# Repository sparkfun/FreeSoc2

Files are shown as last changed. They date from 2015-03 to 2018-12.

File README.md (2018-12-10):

SparkFun FreeSoc2
========================================

FreeSoC2 (https://www.sparkfun.com/products/13714)

[*SparkFun FreeSoC2 (DEV-13714)*](https://www.sparkfun.com/products/13714)

The [FreeSoc2 is SparkFun's PSoC5LP development board](https://www.sparkfun.com/products/13714). It features a full onboard debugger, support for 5V and 3.3V IO voltages, and a CY8C5888AXI-LP096 processor with 256kB of flash, 64kB of SRAM and 2kB of EEPROM. The onboard oscillator can drive the processor at up to 80MHz, and the Cortex-M3 core provides superior performance.

The real power of the PSoC5LP isn't in the processor, however. Wrapped around the processor is a rich analog and digital programmable fabric which can be configured to provide many functions which would otherwise need to be realized in code (lowering system performance) or external circuitry (adding cost and board size). In addition, the highly flexible fabric means that most any function can be routed to most any pin, which makes this a wonderful tool for development and allows board layout errors to be solved, at least temporarily, pretty easily.

Repository Contents
-------------------

* **/Hardware** - Eagle design files (.brd, .sch)
* **/Production** - Production panel files (.brd)

Documentation
--------------
* **[Arduino Board Support](https://github.com/sparkfun/PSoC_Arduino_Support)** - Support board files for adding the FreeSoC2 to the Arduino IDE.
* **[Hookup Guide](https://learn.sparkfun.com/tutorials/freesoc2-hookup-guide-v14)** - Basic hookup guide for the FreeSoC2.

Product Versions
----------------
* [DEV-13714](https://www.sparkfun.com/products/13714) - V14
* _[DEV-13229 (RETIRED)](https://www.sparkfun.com/products/13229)- Initial Release_

Version History
---------------
* [v14](https://github.com/sparkfun/FreeSoc2/releases/tag/v14) -  V14 update
* [v01](https://github.com/sparkfun/FreeSoc2/releases/tag/v01) - Initial Release

License Information
-------------------
This product is _**open source**_! 

The **hardware** is released under [Creative Commons ShareAlike 4.0 International](https://creativecommons.org/licenses/by-sa/4.0/).

The **code** is beerware; if you see me (or any other SparkFun employee) at the local, and you've found our code helpful, please buy us a round!

Please use, reuse, and modify these files as you see fit. Please maintain attribution to SparkFun Electronics and release anything derivative under the same license.

Distributed as-is; no warranty is given.

- Your friends at SparkFun.

Collaborators
-------------

Thanks to Jon Moeller, for creating the first FreeSoC board and providing terrific feedback during the development of the FreeSoC2.
Thanks to Cypress Semiconductor, for providing feedback and working with us closely to ensure that the FreeSoC2 was the right product for the time.

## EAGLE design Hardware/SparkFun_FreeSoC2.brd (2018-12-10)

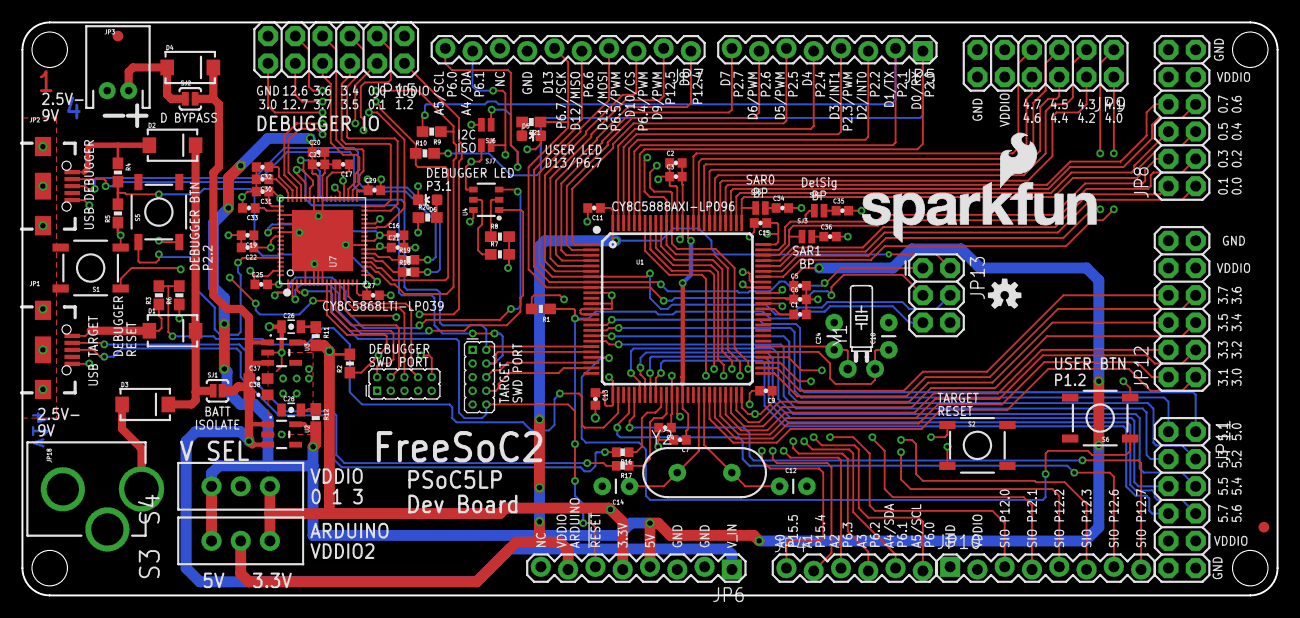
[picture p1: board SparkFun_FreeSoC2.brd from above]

Board: 4 copper layers, 116.8 x 53.3 mm, 110 parts (0 on the bottom side), 127 nets.

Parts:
C1, C2, C4, C5, C7, C16, C17, C19, C20: 1.0uF; 0402-CAP
C3, C6, C9, C11, C13, C15, C21, C22, C23, C25, C27, C29, C30, C31, C32, C33, C34, C35, C36: 0.1uF; 0402-CAP
C12, C14, C18, C24: CAP-PTH-SMALL
C26, C28: 10uF; 0805-CAP
C37: 1.0uF; 0603-CAP
C38: 0.1uF; 0603-CAP
D1, D2, D3, D4: MBRA140; SMA-DIODE
D5, D6: RED; LED-0603
FID1, FID2: FIDUCIAL1X2; FIDUCIAL-1X2
FRAME1, FRAME2, FRAME3: FRAME-LETTERNO_PACKAGE; DUMMY
JP1, JP2: MicroB; USB-B-MICRO-SMD_V03
JP3: JST-2-PTH
JP4: 1X6 FEMALE PTH; 1X06-SIP_LOCK
JP5, JP6: 1X8 FEMALE PTH; 1X08_LOCK
JP7: 1X10 FEMALE PTH; 1X10_LOCK
JP8, JP9, JP11, JP12, JP15: 2X6 FEMALE; 2X6
JP10: 1x8 FEMALE PTH; 1X08_LOCK
JP13: 2X3
JP14, JP17: DNP; 2X5_PTH_SILK_.05
JP18: POWER_JACKPTH_LOCK; POWER_JACK_PTH_LOCK
LOGO1: SFE_LOGO_NAME_FLAME.2_INCH; SFE_LOGO_NAME_FLAME_.2
LOGO2: OSHW-LOGOS; OSHW-LOGO-S
R1, R2: 4.7K; 0603-RES
R3, R4: 10K; 0603-RES
R5, R6: 20k; 0603-RES
R7, R8: 2.2k; 0603-RES
R9, R10, R20, R21: 1K; 0603-RES@1
R11, R12: 0.27; 0603-RES
R16, R17, R18, R19: 22; 0402-RES
S1, S2, S5, S6: SPST-MOM; TACTILE-SWITCH-SMD
S3, S4: SPDT; SWITCH-SPDT_LOCK.007S
SJ1: JUMPER-PAD-2-NC_BY_PASTE; PAD-JUMPER-2-NC_BY_PASTE_YES_SILK
SJ2: JUMPER-PAD-2-NOYES_SILK; PAD-JUMPER-2-NO_YES_SILK
SJ3, SJ4, SJ5, SJ6, SJ7: JUMPER-PAD-2-NO; PAD-JUMPER-2-NO_NO_SILK
STANDOFF1, STANDOFF2, STANDOFF3, STANDOFF4: STAND-OFF
U1: CY8C5888AXI-LP096; TQFP-100-14X14MM
U2: MIC5219 5V; SOT23-5
U3: MIC5219 3.3V; SOT23-5
U4: 2A/20V; SOT26
U7: CY8C5868LTI-LP039; QFN-68
U$1: FOUR_LAYER_WARNING
U$2: CREATIVE_COMMONS@1
Y1: 32.768kHz; TC26H
Y2: HC49US

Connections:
3.3V: C2.1, C3.1, C4.1, C19.1, C21.1, C22.1, JP6.5, R1.2, R2.2, R11.2, S3.3, S4.3, U1.37, U1.88, U3.5, U7.24, U7.59
5V: C5.1, C6.1, C20.1, C23.1, JP6.4, R12.2, S3.1, S4.1, U1.65, U2.5, U7.44
!DEBUG_P2.6_SCL_PU_EN: U4.G2, U7.1
!DEBUG_P2.7_SDA_PU_EN: U4.G1, U7.2
!DEBUG_RESET: JP14.10, R2.1, S1.1, U7.10
!RESET: JP6.6, JP13.5, JP17.10, R1.1, S2.1, U1.15, U7.3
A0: JP4.1, U1.94
A1: JP4.2, U1.93
A2: JP4.3, U1.92
A3: JP4.4, U1.91
A4: JP4.5, JP7.9, SJ7.1, U1.90
A5: JP4.6, JP7.10, SJ6.1, U1.89
ANCHOR_POUR: JP1.SHIELD1, JP1.SHIELD2, JP1.SHIELD3, JP2.SHIELD1, JP2.SHIELD2, JP2.SHIELD3
D0: JP5.1, R10.2, U1.95
D1: JP5.2, R9.2, U1.96
D2: JP5.3, U1.97
D3: JP5.4, U1.98
D4: JP5.5, U1.99
D5: JP5.6, U1.1
D6: JP5.7, U1.2
D7: JP5.8, U1.3
D8: JP7.1, U1.4
D9: JP7.2, U1.5
D10: JP7.3, U1.6
D11: JP7.4, JP13.4, U1.7
D12: JP7.5, JP13.1, U1.8
D13: JP7.6, JP13.3, R21.1, U1.9
DEBUG_BTN: S5.1, U7.64
DEBUG_D+_BUS: JP2.D+1, R18.2
DEBUG_D+_PAD: R18.1, U7.22
DEBUG_D-_BUS: JP2.D-1, R19.2
DEBUG_D-_PAD: R19.1, U7.23
DEBUG_DS_BP: C30.1, U7.51
DEBUG_LED: R20.1, U7.30
DEBUG_P0.0: JP15.3, U7.48
DEBUG_P0.1: JP15.4, U7.49
DEBUG_P1.2: JP15.2, U7.13
DEBUG_P3.0: JP15.12, U7.29
DEBUG_P3.4: JP15.5, U7.33
DEBUG_P3.5: JP15.6, U7.34
DEBUG_P3.6: JP15.7, U7.36
DEBUG_P3.7: JP15.8, U7.37
DEBUG_P12.0_SCL: SJ7.2, U4.D2, U7.39
DEBUG_P12.1_SDA: SJ6.2, U4.D1, U7.38
DEBUG_P12.6_RX: JP15.9, R9.1, U7.20
DEBUG_P12.7_TX: JP15.10, R10.1, U7.21
DEBUG_SAR0_BP: C33.1, U7.53
DEBUG_SAR1_BP: C32.1, U7.50
DEBUG_SWDCK_TCK: JP14.4, U7.12
DEBUG_SWDIO_TMS: JP14.2, U7.11
DEBUG_SWV_TDO: JP14.6, U7.14
DEBUG_TDI: JP14.8, U7.15
GND: C1.2, C2.2, C3.2, C4.2, C5.2, C6.2, C7.2, C9.2, C11.2, C12.2, C13.2, C14.2, C15.2, C16.2, C17.2, C18.2, C19.2, C20.2, C21.2, C22.2, C23.2, C24.2, C25.2, C26.1, C27.2, C28.1, C29.2, C30.2, C31.2, C32.2, C33.2, C34.2, C35.2, C36.2, C37.2, C38.2, D5.C, D6.C, JP1.GND1, JP2.GND1, JP3.1, JP6.2, JP6.3, JP7.7, JP8.11, JP8.12, JP9.11, JP9.12, JP10.1, JP11.11, JP11.12, JP12.11, JP12.12, JP13.6, JP14.3, JP14.5, JP14.7, JP14.9, JP15.11, JP17.3, JP17.5, JP17.7, JP17.9, JP18.GND, JP18.GNDBREAK, R5.1, R6.1, S1.3, S2.3, S5.3, S6.3, U1.10, U1.12, U1.13, U1.14, U1.38, U1.64, U1.66, U1.87, U2.2, U3.2, U7.5, U7.7, U7.8, U7.9, U7.25, U7.43, U7.45, U7.54, U7.56, U7.58, U7.69
unnamed: C26.2, R11.1
unnamed: C34.1, SJ5.2
unnamed: C35.1, SJ4.2
unnamed: C36.1, SJ3.2
unnamed: C28.2, R12.1
unnamed: R8.1, U4.S2
unnamed: R7.1, U4.S1
unnamed: D3.A, JP18.PWR
unnamed: C16.1, U7.26, U7.57
unnamed: D1.C, D2.C, D3.C, SJ1.1
unnamed: D4.A, JP3.2, SJ2.1
unnamed: D6.A, R20.2
unnamed: D5.A, R21.2
unnamed: C17.1, U7.42
P0.0: JP8.1, U1.71
P0.1: JP8.2, U1.72
P0.2: JP8.3, SJ3.1, U1.73
P0.3: JP8.4, SJ4.1, U1.74
P0.4: JP8.5, SJ5.1, U1.76
P0.5: JP8.6, U1.77
P0.6: JP8.7, U1.78
P0.7: JP8.8, U1.79
P1.0: JP17.2, U1.20, U7.46
P1.1: JP17.4, U1.21, U7.47
P1.2: S6.1, U1.22
P1.3: JP17.6, U1.23
P1.4: JP17.8, U1.24
P3.0: JP12.1, U1.44
P3.1: JP12.2, U1.45
P3.2: JP12.3, U1.46
P3.3: JP12.4, U1.47
P3.4: JP12.5, U1.48
P3.5: JP12.6, U1.49
P3.6: JP12.7, U1.51
P3.7: JP12.8, U1.52
P4.0: JP9.2, U1.69
P4.1: JP9.1, U1.70
P4.2: JP9.4, U1.80
P4.3: JP9.3, U1.81
P4.4: JP9.6, U1.82
P4.5: JP9.5, U1.83
P4.6: JP9.8, U1.84
P4.7: JP9.7, U1.85
P5.0: JP11.2, U1.16
P5.1: JP11.1, U1.17
P5.2: JP11.4, U1.18
P5.3: JP11.3, U1.19
P5.4: JP11.6, U1.31
P5.5: JP11.5, U1.32
P5.6: JP11.8, U1.33
P5.7: JP11.7, U1.34
P12.0: JP10.3, U1.53
P12.1: JP10.4, U1.54
P12.2: JP10.5, U1.67
P12.3: JP10.6, U1.68
P12.6: JP10.7, U1.29
P12.7: JP10.8, U1.30
P15.0: C14.1, U1.42, Y2.1
P15.1: C12.1, U1.43, Y2.2
P15.2: C18.1, U1.55, Y1.2
P15.3: C24.1, U1.56, Y1.1
PSOC_D+_BUS: JP1.D+1, R16.2
PSOC_D+_PAD: R16.1, U1.35
PSOC_D-_BUS: JP1.D-1, R17.2
PSOC_D-_PAD: R17.1, U1.36
VCCA: C1.1, U1.63
VCCD: C7.1, U1.39, U1.86
VDDIO: C9.1, C13.1, C15.1, C25.1, C27.1, C29.1, C31.1, JP8.9, JP8.10, JP9.9, JP9.10, JP10.2, JP11.9, JP11.10, JP12.9, JP12.10, JP14.1, JP15.1, JP17.1, R7.2, R8.2, S4.2, U1.26, U1.50, U1.75, U7.17, U7.35, U7.52, U7.67
VDDIO_ARDUINO: C11.1, JP6.7, JP13.2, S3.2, U1.100
V_BUS_DEBUG: R4.2, R5.2, U7.18
V_BUS_HOST: R3.2, R6.2, U1.27
V_DEBUG: D2.A, JP2.VBUS1, R4.1
V_HOST: D1.A, JP1.VBUS1, R3.1
V_IN: C37.1, C38.1, D4.C, JP6.1, SJ1.2, SJ2.2, U2.1, U2.3, U3.1, U3.3

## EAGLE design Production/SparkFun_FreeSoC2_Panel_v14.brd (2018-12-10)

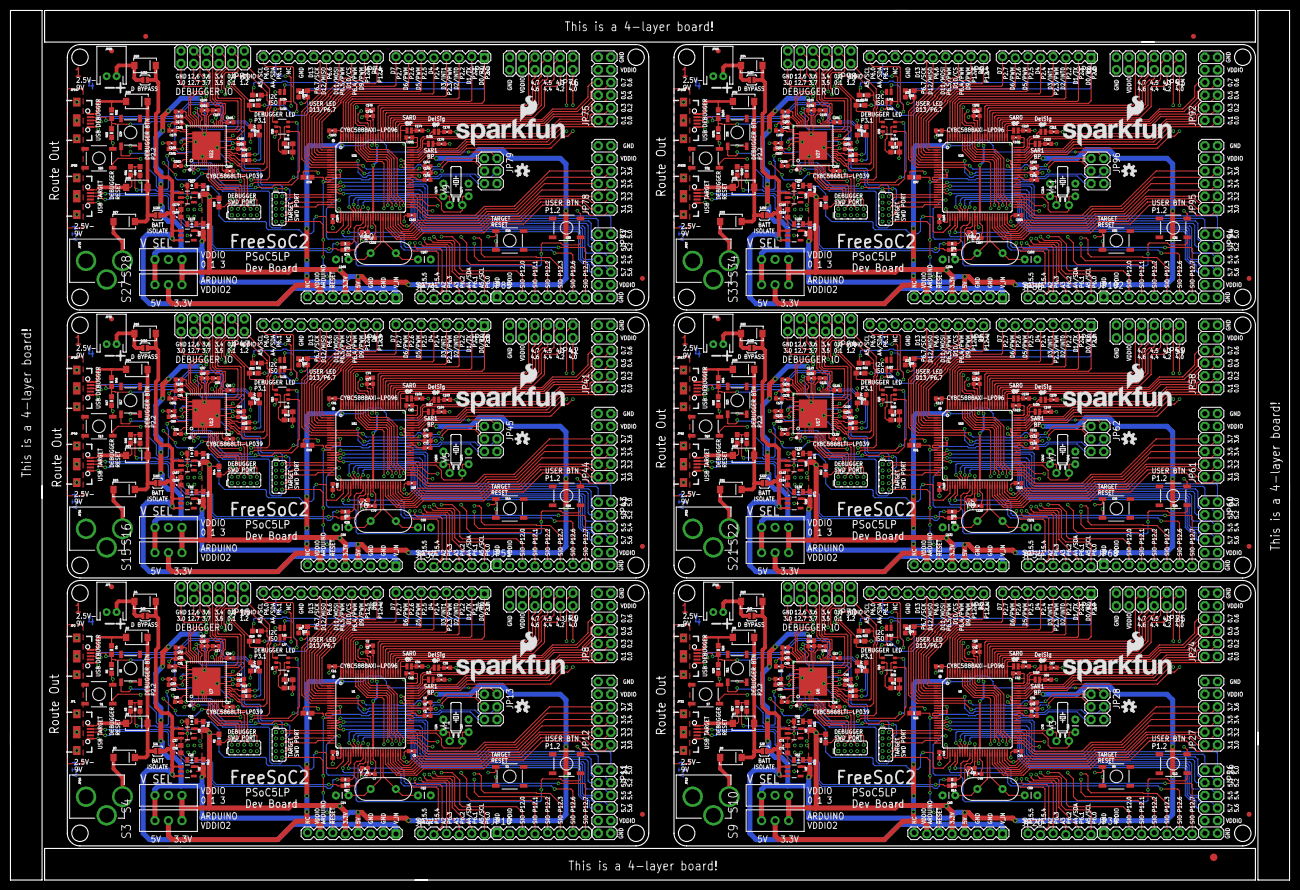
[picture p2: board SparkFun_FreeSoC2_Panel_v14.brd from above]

Board: 4 copper layers, 257.0 x 174.8 mm, 633 parts (0 on the bottom side), 762 nets.

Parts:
C1, C2, C4, C5, C7, C8, C10, C16, C17, C19, C20, C39, C42, C43, C48, C49, C50, C51, C73, C74, C75, C78, C79, C84, C85, C86, C87, C109, C110, C111, C114, C115, C120, C121, C122, C123, C145, C146, C147, C150, C151, C156, C157, C158, C159, C181, C182, C183, C186, C187, C192, C193, C194, C195: 1.0uF; 0402-CAP
C3, C6, C9, C11, C13, C15, C21, C22, C23, C25, C27, C29, C30, C31, C32, C33, C34, C35, C36, C40, C41, C44, C45, C46, C47, C52, C53, C54, C55, C56, C57, C58, C63, C64, C65, C66, C67, C68, C76, C77, C80, C81, C82, C83, C88, C89, C90, C91, C92, C93, C94, C99, C100, C101, C102, C103, C104, C112, C113, C116, C117, C118, C119, C124, C125, C126, C127, C128, C129, C130, C135, C136, C137, C138, C139, C140, C148, C149, C152, C153, C154, C155, C160, C161, C162, C163, C164, C165, C166, C171, C172, C173, C174, C175, C176, C184, C185, C188, C189, C190, C191, C196, C197, C198, C199, C200, C201, C202, C207, C208, C209, C210, C211, C212: 0.1uF; 0402-CAP
C12, C14, C18, C24, C59, C60, C69, C70, C95, C96, C105, C106, C131, C132, C141, C142, C167, C168, C177, C178, C203, C204, C213, C214: CAP-PTH-SMALL
C26, C28, C61, C62, C97, C98, C133, C134, C169, C170, C205, C206: 10uF; 0805-CAP
C37, C71, C107, C143, C179, C215: 1.0uF; 0603-CAP
C38, C72, C108, C144, C180, C216: 0.1uF; 0603-CAP
D1, D2, D3, D4, D7, D8, D9, D10, D13, D14, D15, D16, D19, D20, D21, D22, D25, D26, D27, D28, D31, D32, D33, D34: MBRA140; SMA-DIODE
D5, D6, D11, D12, D17, D18, D23, D24, D29, D30, D35, D36: RED; LED-0603
E$1: FIDUCIAL-1.5X3
E$7, E$8: FIDUCIAL-1X2
FID1, FID2, FID3, FID4, FID5, FID6, FID7, FID8, FID9, FID10, FID11, FID12: FIDUCIAL1X2; FIDUCIAL-1X2
JP1, JP2, JP32, JP33, JP49, JP50, JP66, JP67, JP83, JP84, JP100, JP101: MicroB; USB-B-MICRO-SMD_V03
JP3, JP16, JP35, JP52, JP69, JP86: JST-2-PTH
JP4, JP20, JP37, JP54, JP71, JP88: 1X6 FEMALE PTH; 1X06-SIP_LOCK
JP5, JP6, JP21, JP22, JP38, JP39, JP55, JP56, JP72, JP73, JP89, JP90: 1X8 FEMALE PTH; 1X08_LOCK
JP7, JP23, JP40, JP57, JP74, JP91: 1X10 FEMALE PTH; 1X10_LOCK
JP8, JP9, JP11, JP12, JP15, JP24, JP25, JP26, JP27, JP30, JP41, JP42, JP43, JP44, JP47, JP58, JP59, JP60, JP61, JP64, JP75, JP76, JP77, JP78, JP81, JP92, JP93, JP94, JP95, JP98: 2X6 FEMALE; 2X6
JP10, JP34, JP51, JP68, JP85, JP102: 1x8 FEMALE PTH; 1X08_LOCK
JP13, JP28, JP45, JP62, JP79, JP96: 2X3
JP14, JP17, JP29, JP31, JP46, JP48, JP63, JP65, JP80, JP82, JP97, JP99: DNP; 2X5_PTH_SILK_.05
JP18, JP19, JP36, JP53, JP70, JP87: POWER_JACKPTH_LOCK; POWER_JACK_PTH_LOCK
LOGO1, LOGO3, LOGO5, LOGO7, LOGO9, LOGO11: SFE_LOGO_NAME_FLAME.2_INCH; SFE_LOGO_NAME_FLAME_.2
LOGO2, LOGO4, LOGO6, LOGO8, LOGO10, LOGO12: OSHW-LOGOS; OSHW-LOGO-S
R1, R2, R25, R26, R43, R44, R61, R62, R79, R80, R97, R98: 4.7K; 0603-RES
R3, R4, R27, R28, R45, R46, R63, R64, R81, R82, R99, R100: 10K; 0603-RES
R5, R6, R29, R30, R47, R48, R65, R66, R83, R84, R101, R102: 20k; 0603-RES
R7, R8, R31, R32, R49, R50, R67, R68, R85, R86, R103, R104: 2.2k; 0603-RES
R9, R10, R20, R21, R23, R24, R33, R34, R41, R42, R51, R52, R59, R60, R69, R70, R77, R78, R87, R88, R95, R96, R105, R106: 1K; 0603-RES@1
R11, R12, R35, R36, R53, R54, R71, R72, R89, R90, R107, R108: 0.27; 0603-RES
R13, R14, R15, R16, R17, R18, R19, R22, R37, R38, R39, R40, R55, R56, R57, R58, R73, R74, R75, R76, R91, R92, R93, R94: 22; 0402-RES
S1, S2, S5, S6, S7, S8, S11, S12, S13, S14, S17, S18, S19, S20, S23, S24, S25, S26, S29, S30, S31, S32, S35, S36: SPST-MOM; TACTILE-SWITCH-SMD
S3, S4, S9, S10, S15, S16, S21, S22, S27, S28, S33, S34: SPDT; SWITCH-SPDT_LOCK.007S
SJ1, SJ8, SJ15, SJ22, SJ29, SJ36: JUMPER-PAD-2-NC_BY_PASTE; PAD-JUMPER-2-NC_BY_PASTE_YES_SILK
SJ2, SJ9, SJ16, SJ23, SJ30, SJ37: JUMPER-PAD-2-NOYES_SILK; PAD-JUMPER-2-NO_YES_SILK
SJ3, SJ4, SJ5, SJ6, SJ7, SJ10, SJ11, SJ12, SJ13, SJ14, SJ17, SJ18, SJ19, SJ20, SJ21, SJ24, SJ25, SJ26, SJ27, SJ28, SJ31, SJ32, SJ33, SJ34, SJ35, SJ38, SJ39, SJ40, SJ41, SJ42: JUMPER-PAD-2-NO; PAD-JUMPER-2-NO_NO_SILK
STANDOFF1, STANDOFF2, STANDOFF3, STANDOFF4, STANDOFF5, STANDOFF6, STANDOFF7, STANDOFF8, STANDOFF9, STANDOFF10, STANDOFF11, STANDOFF12, STANDOFF13, STANDOFF14, STANDOFF15, STANDOFF16, STANDOFF17, STANDOFF18, STANDOFF19, STANDOFF20, STANDOFF21, STANDOFF22, STANDOFF23, STANDOFF24: STAND-OFF
U1, U5, U11, U16, U21, U26: CY8C5888AXI-LP096; TQFP-100-14X14MM
U2, U8, U13, U18, U23, U28: MIC5219 5V; SOT23-5
U3, U9, U14, U19, U24, U29: MIC5219 3.3V; SOT23-5
U4, U10, U15, U20, U25, U30: 2A/20V; SOT26
U6, U7, U12, U17, U22, U27: CY8C5868LTI-LP039; QFN-68
Y1, Y3, Y5, Y7, Y9, Y11: 32.768kHz; TC26H
Y2, Y4, Y6, Y8, Y10, Y12: HC49US

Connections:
3.3V: C2.1, C3.1, C4.1, C19.1, C21.1, C22.1, JP6.5, R1.2, R2.2, R11.2, S3.3, S4.3, U1.37, U1.88, U3.5, U7.24, U7.59
3.3V1: C10.1, C41.1, C42.1, C50.1, C52.1, C53.1, JP22.5, R25.2, R26.2, R35.2, S9.3, S10.3, U5.37, U5.88, U6.24, U6.59, U9.5
3.3V2: C74.1, C77.1, C78.1, C86.1, C88.1, C89.1, JP39.5, R43.2, R44.2, R53.2, S15.3, S16.3, U11.37, U11.88, U12.24, U12.59, U14.5
3.3V3: C110.1, C113.1, C114.1, C122.1, C124.1, C125.1, JP56.5, R61.2, R62.2, R71.2, S21.3, S22.3, U16.37, U16.88, U17.24, U17.59, U19.5
3.3V4: C146.1, C149.1, C150.1, C158.1, C160.1, C161.1, JP73.5, R79.2, R80.2, R89.2, S27.3, S28.3, U21.37, U21.88, U22.24, U22.59, U24.5
3.3V5: C182.1, C185.1, C186.1, C194.1, C196.1, C197.1, JP90.5, R97.2, R98.2, R107.2, S33.3, S34.3, U26.37, U26.88, U27.24, U27.59, U29.5
5V: C5.1, C6.1, C20.1, C23.1, JP6.4, R12.2, S3.1, S4.1, U1.65, U2.5, U7.44
5V1: C39.1, C40.1, C51.1, C54.1, JP22.4, R36.2, S9.1, S10.1, U5.65, U6.44, U8.5
5V2: C75.1, C76.1, C87.1, C90.1, JP39.4, R54.2, S15.1, S16.1, U11.65, U12.44, U13.5
5V3: C111.1, C112.1, C123.1, C126.1, JP56.4, R72.2, S21.1, S22.1, U16.65, U17.44, U18.5
5V4: C147.1, C148.1, C159.1, C162.1, JP73.4, R90.2, S27.1, S28.1, U21.65, U22.44, U23.5
5V5: C183.1, C184.1, C195.1, C198.1, JP90.4, R108.2, S33.1, S34.1, U26.65, U27.44, U28.5
!DEBUG_P2.6_SCL_PU_EN: U4.G2, U7.1
!DEBUG_P2.6_SCL_PU_EN1: U6.1, U10.G2
!DEBUG_P2.6_SCL_PU_EN2: U12.1, U15.G2
!DEBUG_P2.6_SCL_PU_EN3: U17.1, U20.G2
!DEBUG_P2.6_SCL_PU_EN4: U22.1, U25.G2
!DEBUG_P2.6_SCL_PU_EN5: U27.1, U30.G2
!DEBUG_P2.7_SDA_PU_EN: U4.G1, U7.2
!DEBUG_P2.7_SDA_PU_EN1: U6.2, U10.G1
!DEBUG_P2.7_SDA_PU_EN2: U12.2, U15.G1
!DEBUG_P2.7_SDA_PU_EN3: U17.2, U20.G1
!DEBUG_P2.7_SDA_PU_EN4: U22.2, U25.G1
!DEBUG_P2.7_SDA_PU_EN5: U27.2, U30.G1
!DEBUG_RESET: JP14.10, R2.1, S1.1, U7.10
!DEBUG_RESET1: JP29.10, R26.1, S7.1, U6.10
!DEBUG_RESET2: JP46.10, R44.1, S13.1, U12.10
!DEBUG_RESET3: JP63.10, R62.1, S19.1, U17.10
!DEBUG_RESET4: JP80.10, R80.1, S25.1, U22.10
!DEBUG_RESET5: JP97.10, R98.1, S31.1, U27.10
!RESET: JP6.6, JP13.5, JP17.10, R1.1, S2.1, U1.15, U7.3
!RESET1: JP22.6, JP28.5, JP31.10, R25.1, S8.1, U5.15, U6.3
!RESET2: JP39.6, JP45.5, JP48.10, R43.1, S14.1, U11.15, U12.3
!RESET3: JP56.6, JP62.5, JP65.10, R61.1, S20.1, U16.15, U17.3
!RESET4: JP73.6, JP79.5, JP82.10, R79.1, S26.1, U21.15, U22.3
!RESET5: JP90.6, JP96.5, JP99.10, R97.1, S32.1, U26.15, U27.3
A0: JP4.1, U1.94
A1: JP4.2, U1.93
A2: JP4.3, U1.92
A3: JP4.4, U1.91
A4: JP4.5, JP7.9, SJ7.1, U1.90
A5: JP4.6, JP7.10, SJ6.1, U1.89
A6: JP20.1, U5.94
A7: JP20.2, U5.93
A8: JP20.6, JP23.10, SJ13.1, U5.89
A9: JP20.5, JP23.9, SJ14.1, U5.90
A10: JP20.3, U5.92
A11: JP20.4, U5.91
A12: JP37.1, U11.94
A13: JP37.2, U11.93
A14: JP37.6, JP40.10, SJ20.1, U11.89
A15: JP37.5, JP40.9, SJ21.1, U11.90
A16: JP37.3, U11.92
A17: JP37.4, U11.91
A18: JP54.1, U16.94
A19: JP54.2, U16.93
A20: JP54.6, JP57.10, SJ27.1, U16.89
A21: JP54.5, JP57.9, SJ28.1, U16.90
A22: JP54.3, U16.92
A23: JP54.4, U16.91
A24: JP71.1, U21.94
A25: JP71.2, U21.93
A26: JP71.6, JP74.10, SJ34.1, U21.89
A27: JP71.5, JP74.9, SJ35.1, U21.90
A28: JP71.3, U21.92
A29: JP71.4, U21.91
A30: JP88.1, U26.94
A31: JP88.2, U26.93
A32: JP88.6, JP91.10, SJ41.1, U26.89
A33: JP88.5, JP91.9, SJ42.1, U26.90
A34: JP88.3, U26.92
A35: JP88.4, U26.91
ANCHOR_POUR: JP1.SHIELD1, JP1.SHIELD2, JP1.SHIELD3, JP2.SHIELD1, JP2.SHIELD2, JP2.SHIELD3
ANCHOR_POUR1: JP32.SHIELD1, JP32.SHIELD2, JP32.SHIELD3, JP33.SHIELD1, JP33.SHIELD2, JP33.SHIELD3
ANCHOR_POUR2: JP49.SHIELD1, JP49.SHIELD2, JP49.SHIELD3, JP50.SHIELD1, JP50.SHIELD2, JP50.SHIELD3
ANCHOR_POUR3: JP66.SHIELD1, JP66.SHIELD2, JP66.SHIELD3, JP67.SHIELD1, JP67.SHIELD2, JP67.SHIELD3
ANCHOR_POUR4: JP83.SHIELD1, JP83.SHIELD2, JP83.SHIELD3, JP84.SHIELD1, JP84.SHIELD2, JP84.SHIELD3
ANCHOR_POUR5: JP100.SHIELD1, JP100.SHIELD2, JP100.SHIELD3, JP101.SHIELD1, JP101.SHIELD2, JP101.SHIELD3
D0: JP5.1, R10.2, U1.95
D1: JP5.2, R9.2, U1.96
D2: JP5.3, U1.97
D3: JP5.4, U1.98
D4: JP5.5, U1.99
D5: JP5.6, U1.1
D6: JP5.7, U1.2
D7: JP5.8, U1.3
D8: JP7.1, U1.4
D9: JP7.2, U1.5
D10: JP7.3, U1.6
D11: JP7.4, JP13.4, U1.7
D12: JP7.5, JP13.1, U1.8
D13: JP7.6, JP13.3, R21.1, U1.9
D14: JP21.1, R34.2, U5.95
D15: JP21.2, R33.2, U5.96
D16: JP21.3, U5.97
D17: JP21.4, U5.98
D18: JP21.5, U5.99
D19: JP21.6, U5.1
D20: JP21.7, U5.2
D21: JP21.8, U5.3
D22: JP23.1, U5.4
D23: JP23.2, U5.5
D24: JP23.3, U5.6
D25: JP23.4, JP28.4, U5.7
D26: JP23.5, JP28.1, U5.8
D27: JP23.6, JP28.3, R24.1, U5.9
D28: JP38.1, R52.2, U11.95
D29: JP38.2, R51.2, U11.96
D30: JP38.3, U11.97
D31: JP38.4, U11.98
D32: JP38.5, U11.99
D33: JP38.6, U11.1
D34: JP38.7, U11.2
D35: JP38.8, U11.3
D36: JP40.1, U11.4
D37: JP40.2, U11.5
D38: JP40.3, U11.6
D39: JP40.4, JP45.4, U11.7
D40: JP40.5, JP45.1, U11.8
D41: JP40.6, JP45.3, R42.1, U11.9
D42: JP55.1, R70.2, U16.95
D43: JP55.2, R69.2, U16.96
D44: JP55.3, U16.97
D45: JP55.4, U16.98
D46: JP55.5, U16.99
D47: JP55.6, U16.1
D48: JP55.7, U16.2
D49: JP55.8, U16.3
D50: JP57.1, U16.4
D51: JP57.2, U16.5
D52: JP57.3, U16.6
D53: JP57.4, JP62.4, U16.7
D54: JP57.5, JP62.1, U16.8
D55: JP57.6, JP62.3, R60.1, U16.9
D56: JP72.1, R88.2, U21.95
D57: JP72.2, R87.2, U21.96
D58: JP72.3, U21.97
D59: JP72.4, U21.98
D60: JP72.5, U21.99
D61: JP72.6, U21.1
D62: JP72.7, U21.2
D63: JP72.8, U21.3
D64: JP74.1, U21.4
D65: JP74.2, U21.5
D66: JP74.3, U21.6
D67: JP74.4, JP79.4, U21.7
D68: JP74.5, JP79.1, U21.8
D69: JP74.6, JP79.3, R78.1, U21.9
D70: JP89.1, R106.2, U26.95
D71: JP89.2, R105.2, U26.96
D72: JP89.3, U26.97
D73: JP89.4, U26.98
D74: JP89.5, U26.99
D75: JP89.6, U26.1
D76: JP89.7, U26.2
D77: JP89.8, U26.3
D78: JP91.1, U26.4
D79: JP91.2, U26.5
D80: JP91.3, U26.6
D81: JP91.4, JP96.4, U26.7
D82: JP91.5, JP96.1, U26.8
D83: JP91.6, JP96.3, R96.1, U26.9
DEBUG_BTN: S5.1, U7.64
DEBUG_BTN1: S11.1, U6.64
DEBUG_BTN2: S17.1, U12.64
DEBUG_BTN3: S23.1, U17.64
DEBUG_BTN4: S29.1, U22.64
DEBUG_BTN5: S35.1, U27.64
DEBUG_D+_BUS: JP2.D+1, R18.2
DEBUG_D+_BUS1: JP33.D+1, R15.2
DEBUG_D+_BUS2: JP50.D+1, R39.2
DEBUG_D+_BUS3: JP67.D+1, R57.2
DEBUG_D+_BUS4: JP84.D+1, R75.2
DEBUG_D+_BUS5: JP101.D+1, R93.2
DEBUG_D+_PAD: R18.1, U7.22
DEBUG_D+_PAD1: R15.1, U6.22
DEBUG_D+_PAD2: R39.1, U12.22
DEBUG_D+_PAD3: R57.1, U17.22
DEBUG_D+_PAD4: R75.1, U22.22
DEBUG_D+_PAD5: R93.1, U27.22
DEBUG_D-_BUS: JP2.D-1, R19.2
DEBUG_D-_BUS1: JP33.D-1, R22.2
DEBUG_D-_BUS2: JP50.D-1, R40.2
DEBUG_D-_BUS3: JP67.D-1, R58.2
DEBUG_D-_BUS4: JP84.D-1, R76.2
DEBUG_D-_BUS5: JP101.D-1, R94.2
DEBUG_D-_PAD: R19.1, U7.23
DEBUG_D-_PAD1: R22.1, U6.23
DEBUG_D-_PAD2: R40.1, U12.23
DEBUG_D-_PAD3: R58.1, U17.23
DEBUG_D-_PAD4: R76.1, U22.23
DEBUG_D-_PAD5: R94.1, U27.23
DEBUG_DS_BP: C30.1, U7.51
DEBUG_DS_BP1: C63.1, U6.51
DEBUG_DS_BP2: C99.1, U12.51
DEBUG_DS_BP3: C135.1, U17.51
DEBUG_DS_BP4: C171.1, U22.51
DEBUG_DS_BP5: C207.1, U27.51
DEBUG_LED: R20.1, U7.30
DEBUG_LED1: R23.1, U6.30
DEBUG_LED2: R41.1, U12.30
DEBUG_LED3: R59.1, U17.30
DEBUG_LED4: R77.1, U22.30
DEBUG_LED5: R95.1, U27.30
DEBUG_P0.0: JP15.3, U7.48
DEBUG_P0.1: JP15.4, U7.49
DEBUG_P0.2: JP30.3, U6.48
DEBUG_P0.3: JP30.4, U6.49
DEBUG_P0.4: JP47.3, U12.48
DEBUG_P0.5: JP47.4, U12.49
DEBUG_P0.6: JP64.3, U17.48
DEBUG_P0.7: JP64.4, U17.49
DEBUG_P0.8: JP81.3, U22.48
DEBUG_P0.9: JP81.4, U22.49
DEBUG_P0.10: JP98.3, U27.48
DEBUG_P0.11: JP98.4, U27.49
DEBUG_P1.1: JP30.2, U6.13
DEBUG_P1.2: JP15.2, U7.13
DEBUG_P1.3: JP47.2, U12.13
DEBUG_P1.4: JP64.2, U17.13
DEBUG_P1.5: JP81.2, U22.13
DEBUG_P1.6: JP98.2, U27.13
DEBUG_P3.0: JP15.12, U7.29
DEBUG_P3.1: JP30.5, U6.33
DEBUG_P3.2: JP30.6, U6.34
DEBUG_P3.3: JP30.7, U6.36
DEBUG_P3.4: JP15.5, U7.33
DEBUG_P3.5: JP15.6, U7.34
DEBUG_P3.6: JP15.7, U7.36
DEBUG_P3.7: JP15.8, U7.37
DEBUG_P3.8: JP30.8, U6.37
DEBUG_P3.9: JP30.12, U6.29
DEBUG_P3.10: JP47.5, U12.33
DEBUG_P3.11: JP47.6, U12.34
DEBUG_P3.12: JP47.7, U12.36
DEBUG_P3.13: JP47.8, U12.37
DEBUG_P3.14: JP47.12, U12.29
DEBUG_P3.15: JP64.5, U17.33
DEBUG_P3.16: JP64.6, U17.34
DEBUG_P3.17: JP64.7, U17.36
DEBUG_P3.18: JP64.8, U17.37
DEBUG_P3.19: JP64.12, U17.29
DEBUG_P3.20: JP81.5, U22.33
DEBUG_P3.21: JP81.6, U22.34
DEBUG_P3.22: JP81.7, U22.36
DEBUG_P3.23: JP81.8, U22.37
DEBUG_P3.24: JP81.12, U22.29
DEBUG_P3.25: JP98.5, U27.33
DEBUG_P3.26: JP98.6, U27.34
DEBUG_P3.27: JP98.7, U27.36
DEBUG_P3.28: JP98.8, U27.37
DEBUG_P3.29: JP98.12, U27.29
DEBUG_P12.0_SCL: SJ7.2, U4.D2, U7.39
DEBUG_P12.0_SCL1: SJ14.2, U6.39, U10.D2
DEBUG_P12.0_SCL2: SJ21.2, U12.39, U15.D2
DEBUG_P12.0_SCL3: SJ28.2, U17.39, U20.D2
DEBUG_P12.0_SCL4: SJ35.2, U22.39, U25.D2
DEBUG_P12.0_SCL5: SJ42.2, U27.39, U30.D2
DEBUG_P12.1_SDA: SJ6.2, U4.D1, U7.38
DEBUG_P12.1_SDA1: SJ13.2, U6.38, U10.D1
DEBUG_P12.1_SDA2: SJ20.2, U12.38, U15.D1
DEBUG_P12.1_SDA3: SJ27.2, U17.38, U20.D1
DEBUG_P12.1_SDA4: SJ34.2, U22.38, U25.D1
DEBUG_P12.1_SDA5: SJ41.2, U27.38, U30.D1
DEBUG_P12.6_RX: JP15.9, R9.1, U7.20
DEBUG_P12.6_RX1: JP30.9, R33.1, U6.20
DEBUG_P12.6_RX2: JP47.9, R51.1, U12.20
DEBUG_P12.6_RX3: JP64.9, R69.1, U17.20
DEBUG_P12.6_RX4: JP81.9, R87.1, U22.20
DEBUG_P12.6_RX5: JP98.9, R105.1, U27.20
DEBUG_P12.7_TX: JP15.10, R10.1, U7.21
DEBUG_P12.7_TX1: JP30.10, R34.1, U6.21
DEBUG_P12.7_TX2: JP47.10, R52.1, U12.21
DEBUG_P12.7_TX3: JP64.10, R70.1, U17.21
DEBUG_P12.7_TX4: JP81.10, R88.1, U22.21
DEBUG_P12.7_TX5: JP98.10, R106.1, U27.21
DEBUG_SAR0_BP: C33.1, U7.53
DEBUG_SAR0_BP1: C65.1, U6.53
DEBUG_SAR0_BP2: C101.1, U12.53
DEBUG_SAR0_BP3: C137.1, U17.53
DEBUG_SAR0_BP4: C173.1, U22.53
DEBUG_SAR0_BP5: C209.1, U27.53
DEBUG_SAR1_BP: C32.1, U7.50
DEBUG_SAR1_BP1: C64.1, U6.50
DEBUG_SAR1_BP2: C100.1, U12.50
DEBUG_SAR1_BP3: C136.1, U17.50
DEBUG_SAR1_BP4: C172.1, U22.50
DEBUG_SAR1_BP5: C208.1, U27.50
DEBUG_SWDCK_TCK: JP14.4, U7.12
DEBUG_SWDCK_TCK1: JP29.4, U6.12
DEBUG_SWDCK_TCK2: JP46.4, U12.12
DEBUG_SWDCK_TCK3: JP63.4, U17.12
DEBUG_SWDCK_TCK4: JP80.4, U22.12
DEBUG_SWDCK_TCK5: JP97.4, U27.12
DEBUG_SWDIO_TMS: JP14.2, U7.11
DEBUG_SWDIO_TMS1: JP29.2, U6.11
DEBUG_SWDIO_TMS2: JP46.2, U12.11
DEBUG_SWDIO_TMS3: JP63.2, U17.11
DEBUG_SWDIO_TMS4: JP80.2, U22.11
DEBUG_SWDIO_TMS5: JP97.2, U27.11
DEBUG_SWV_TDO: JP14.6, U7.14
DEBUG_SWV_TDO1: JP29.6, U6.14
DEBUG_SWV_TDO2: JP46.6, U12.14
DEBUG_SWV_TDO3: JP63.6, U17.14
DEBUG_SWV_TDO4: JP80.6, U22.14
DEBUG_SWV_TDO5: JP97.6, U27.14
DEBUG_TDI: JP14.8, U7.15
DEBUG_TDI1: JP29.8, U6.15
DEBUG_TDI2: JP46.8, U12.15
DEBUG_TDI3: JP63.8, U17.15
DEBUG_TDI4: JP80.8, U22.15
DEBUG_TDI5: JP97.8, U27.15
GND: C1.2, C2.2, C3.2, C4.2, C5.2, C6.2, C7.2, C9.2, C11.2, C12.2, C13.2, C14.2, C15.2, C16.2, C17.2, C18.2, C19.2, C20.2, C21.2, C22.2, C23.2, C24.2, C25.2, C26.1, C27.2, C28.1, C29.2, C30.2, C31.2, C32.2, C33.2, C34.2, C35.2, C36.2, C37.2, C38.2, D5.C, D6.C, JP1.GND1, JP2.GND1, JP3.1, JP6.2, JP6.3, JP7.7, JP8.11, JP8.12, JP9.11, JP9.12, JP10.1, JP11.11, JP11.12, JP12.11, JP12.12, JP13.6, JP14.3, JP14.5, JP14.7, JP14.9, JP15.11, JP17.3, JP17.5, JP17.7, JP17.9, JP18.GND, JP18.GNDBREAK, R5.1, R6.1, S1.3, S2.3, S5.3, S6.3, U1.10, U1.12, U1.13, U1.14, U1.38, U1.64, U1.66, U1.87, U2.2, U3.2, U7.5, U7.7, U7.8, U7.9, U7.25, U7.43, U7.45, U7.54, U7.56, U7.58, U7.69
GND1: C8.2, C10.2, C39.2, C40.2, C41.2, C42.2, C43.2, C44.2, C45.2, C46.2, C47.2, C48.2, C49.2, C50.2, C51.2, C52.2, C53.2, C54.2, C55.2, C56.2, C57.2, C58.2, C59.2, C60.2, C61.1, C62.1, C63.2, C64.2, C65.2, C66.2, C67.2, C68.2, C69.2, C70.2, C71.2, C72.2, D11.C, D12.C, JP16.1, JP19.GND, JP19.GNDBREAK, JP22.2, JP22.3, JP23.7, JP24.11, JP24.12, JP25.11, JP25.12, JP26.11, JP26.12, JP27.11, JP27.12, JP28.6, JP29.3, JP29.5, JP29.7, JP29.9, JP30.11, JP31.3, JP31.5, JP31.7, JP31.9, JP32.GND1, JP33.GND1, JP34.1, R29.1, R30.1, S7.3, S8.3, S11.3, S12.3, U5.10, U5.12, U5.13, U5.14, U5.38, U5.64, U5.66, U5.87, U6.5, U6.7, U6.8, U6.9, U6.25, U6.43, U6.45, U6.54, U6.56, U6.58, U6.69, U8.2, U9.2
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

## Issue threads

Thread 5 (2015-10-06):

v13 Proto issues

ericorosel, 2015-10-06:
Just two:

(1) Got some weird net action going on on the input side of the vregs (SCH page(2)), it looks like the vreg symbols got moved around a bit.

(2) The two new resistors off of the vregs need the PROD_ID in the attributes. As far as I'm concerned, as long as this is fixed before REDs I'm cool with it staying as is through the protos if we want to get these out ASAP.

that's it!

mhord, 2015-10-06:
Fixed and pushed.

Closed 2015-10-06.

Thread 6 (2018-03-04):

Setting up FreeSoc2 in Arduino ... C compiler setup issues ... please help

subu65, 2018-03-04:
Hi Everyone,
I picked up the FreeSoc2 board from Embedded World and tried setting up, using the guide from SparkFun, but i keep getting the following error:

Arduino: 1.8.5 (Windows 10), Board: "PSoC Dev Board"

**Warning: platform.txt from core 'SparkFun PSoC Development Boards' contains deprecated recipe.ar.pattern="{compiler.path}{compiler.ar.cmd}" {compiler.ar.flags} {compiler.ar.extra_flags} "{build.path}/{archive_file}" "{object_file}", automatically converted to recipe.ar.pattern="{compiler.path}{compiler.ar.cmd}" {compiler.ar.flags} {compiler.ar.extra_flags} "{archive_file_path}" "{object_file}". Consider upgrading this core.
exec: "/hardware/tools/psoc/bin/arm-none-eabi-gcc": file does not exist
Error compiling for board PSoC Dev Board.**

I tried to make changes to Platform.txt, for the C compiler path name, but still get this message.

Can anyone please help !! Appreciate your support

subu65, 2018-03-10:
Hi Dave,

Thank you so much. The 1st half worked, at least the complication works.

Can you please let me know what was the programmer option you choose to upload the sketch to the board?

Thank you for your help.

Subu
________________________________
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

mhord, 2018-03-13:
The bootloader for the FreeSoC2 is designed to operate with the AVR109 protocol, the same thing that Arduino Uno and other similar boards use.

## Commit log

2014-10-21 Commit first schematic
    [freesoc_sparkfun.brd, freesoc_sparkfun.sch]
2014-10-22 Add some bypass caps
    [freesoc_sparkfun.brd, freesoc_sparkfun.sch]
2014-10-30 Routed, ready for review.
    [freesoc_sparkfun.brd, freesoc_sparkfun.sch]
2014-11-10 Routed, with board checklist.
    [board_checklist.csv, freesoc_sparkfun.brd, freesoc_sparkfun.sch]
2014-11-11 Ready for QC review
    [board_checklist.csv, freesoc_sparkfun.brd, freesoc_sparkfun.sch]
2014-11-14 Fixed stuff from QC spreadsheet review.
    [freesoc_sparkfun.brd, freesoc_sparkfun.sch]
2014-11-17 Files as submitted to Advanced, with prototype Gerbers
    [freesoc_sparkfun.brd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]
2015-01-12 Files changed after v01 feedback, to add kitprog ID pins
    [freesoc_sparkfun.brd, freesoc_sparkfun.sch]
2015-01-19 Changes for v02 in, review
    [freesoc_sparkfun.brd, freesoc_sparkfun.sch]
2015-01-19 ready for protos v02
    [board_checklist.csv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]
2015-01-20 Up to V02, checklist and peer review completed
    [board_checklist.csv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]
2015-02-10 v10 almost ready
    [freesoc_sparkfun.brd, freesoc_sparkfun.sch]
2015-02-11 Changes for v10, pre-review
    [freesoc_sparkfun.brd, freesoc_sparkfun.sch]
2015-02-11 Renamed files, added FreeSoC2 name
    [SparkFun_FreeSoC2.brd, SparkFun_FreeSoC2.sch, board_checklist.csv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]
2015-02-12 Add UART/I2C bridge, lock headers, IC names
    [SparkFun_FreeSoC2.brd, SparkFun_FreeSoC2.sch, board_checklist.csv]
2015-02-13 Fixed a few small errors from staggered headers.
    [SparkFun_FreeSoC2.brd]
2015-02-13 Revisions from QC check
    [SparkFun_FreeSoC2.brd, SparkFun_FreeSoC2.sch]
2015-02-13 Fixed silk/part value for target IC
    [SparkFun_FreeSoC2.brd, SparkFun_FreeSoC2.sch]
2015-02-13 Add prod_id info to some parts
    [SparkFun_FreeSoC2.brd, SparkFun_FreeSoC2.sch]
2015-02-25 created massive panel v10
    [SparkFun_FreeSoC2_Panel_v10.brd]
2015-03-20 Rev to 11 to fix rev #, layers issue
    [SparkFun_FreeSoC2.brd, SparkFun_FreeSoC2.sch]
2015-03-20 deleted old panel with missing ground
    [SparkFun_FreeSoC2_Panel_v10.brd]
2015-03-20 created panel v11
    includes gerbers for verification
    [SparkFun_FreeSoC2_Panel_v11.brd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]
2015-04-10 Rev to include changes from production
    [SparkFun_FreeSoC2.brd, SparkFun_FreeSoC2.sch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]
2015-05-19 Revisions from first production run
    [SparkFun_FreeSoC2.brd, SparkFun_FreeSoC2.sch]
2015-06-30 Changes from user feedback and experience
    [SparkFun_FreeSoC2.brd, SparkFun_FreeSoC2.sch]
2015-06-30 Last of changes before protos
    [SparkFun_FreeSoC2.brd]
2015-07-13 Enthickened lines on logos for better rendering
    [SparkFun_FreeSoC2.brd, SparkFun_FreeSoC2.sch]
2015-08-27 Chg to V13, fix traces over vias
    [SparkFun_FreeSoC2.brd, SparkFun_FreeSoC2.sch]
2015-09-08 Advance v# on pgs 2 and 3
    [SparkFun_FreeSoC2.brd, SparkFun_FreeSoC2.sch]
2015-09-16 Changed value of DNP caps to DNP
    [SparkFun_FreeSoC2.brd, SparkFun_FreeSoC2.sch]
2015-09-28 Add small series resistor on regulator bypass caps
    [SparkFun_FreeSoC2.brd, SparkFun_FreeSoC2.sch]
2015-10-06 Schematic fixes from QC feedback
    [SparkFun_FreeSoC2.brd, SparkFun_FreeSoC2.sch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]
2015-11-11 Fix USB port anchoring to isolate shield from ground
    [SparkFun_FreeSoC2.brd, SparkFun_FreeSoC2.sch]
2016-04-01 created panel v14
    [SparkFun_FreeSoC2_Panel_v11.brd, SparkFun_FreeSoC2_Panel_v14.brd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]
2018-12-10 Rename Eagle Files
    Merge conflict. Updating names and saving before merging V14.
    [SparkFun_FreeSoC2_V1.sch]
2018-12-10 Remove Old Eagle Files
    Remove Eagle Files to remedy merge conflict.
    [SparkFun_FreeSoC2_V1.brd, SparkFun_FreeSoC2_V1.sch]
2018-12-10 V14 Files
    Mike Hord's Fix USB port anchoring to isolate shield from ground (from the V12 branch). There was a merge conflict so I downloaded the files manually to my computer before re-uploading.
    [SparkFun_FreeSoC2.brd, SparkFun_FreeSoC2.sch]
2018-12-10 Update path
    [SparkFun_FreeSoC2.sch]

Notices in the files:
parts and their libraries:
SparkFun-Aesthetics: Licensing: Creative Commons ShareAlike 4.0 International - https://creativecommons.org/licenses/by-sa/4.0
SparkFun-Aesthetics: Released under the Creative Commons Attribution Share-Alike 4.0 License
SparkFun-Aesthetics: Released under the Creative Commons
